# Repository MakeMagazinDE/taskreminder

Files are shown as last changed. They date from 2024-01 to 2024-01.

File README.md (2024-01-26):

GitHub Logo

Maker Media GmbH
*** 

# Task-Reminder

### Aufgaben, die man nicht im Blick hat, können schnell mal unter den Tisch fallen. Den Task-Reminder mit seinen LEDs kann man jedoch kaum übersehen. Er weiß genau, welche Aufgabe als Nächstes ansteht und leuchtet unermüdlich, bis man sie erledigt hat.

Ergänzend zum Artikel aus der Make 1/24 findest du hier die benötigten MicroPython-Programme für den ESP32, die Formeln für das Google-Sheet sowie die CAD-Daten für die Platine und das Gehäuse des Task-Reminders.

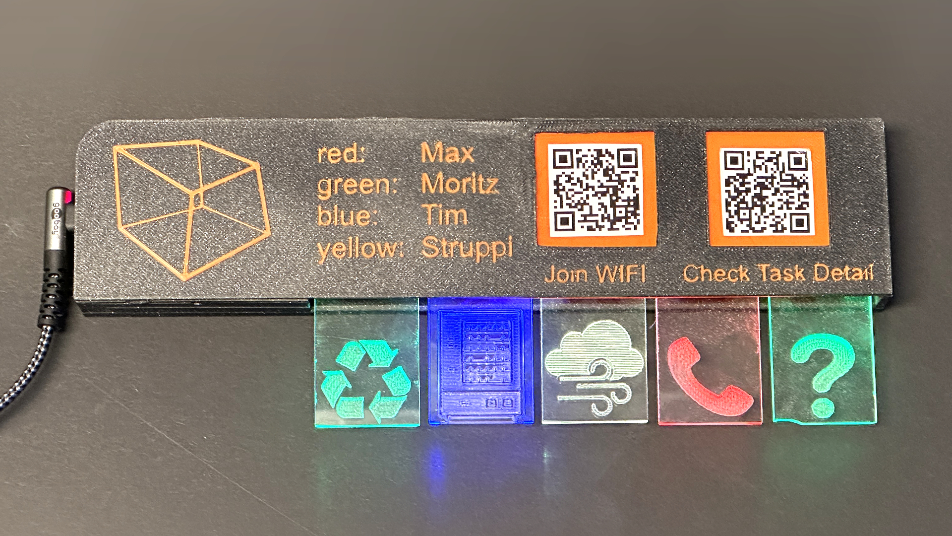
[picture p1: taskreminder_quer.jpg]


Den Artikel mit der Bauanleitung gibt es in der **[Make-Ausgabe 1/24](https://www.heise.de/select/make/2024/1)** zu lesen.

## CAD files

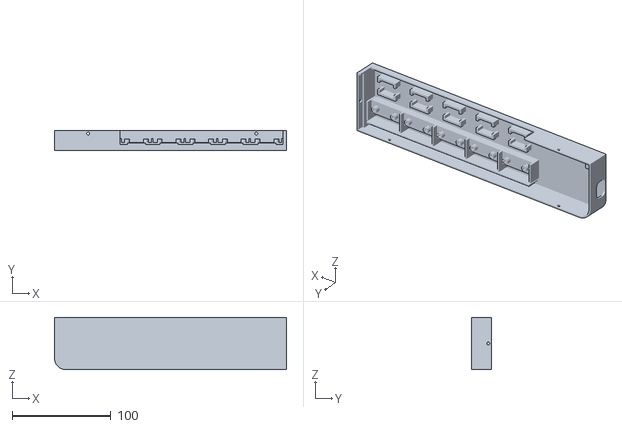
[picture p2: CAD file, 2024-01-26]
CAD/Base.stl
234.8 x 20.0 x 52.8

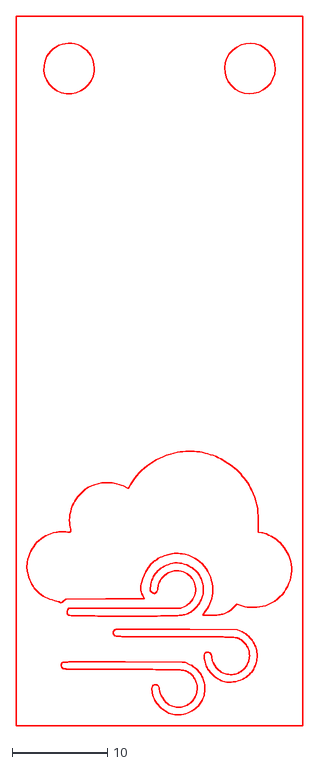
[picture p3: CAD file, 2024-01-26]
CAD/Symbol_FreshAir.dxf
30.1 x 74.5

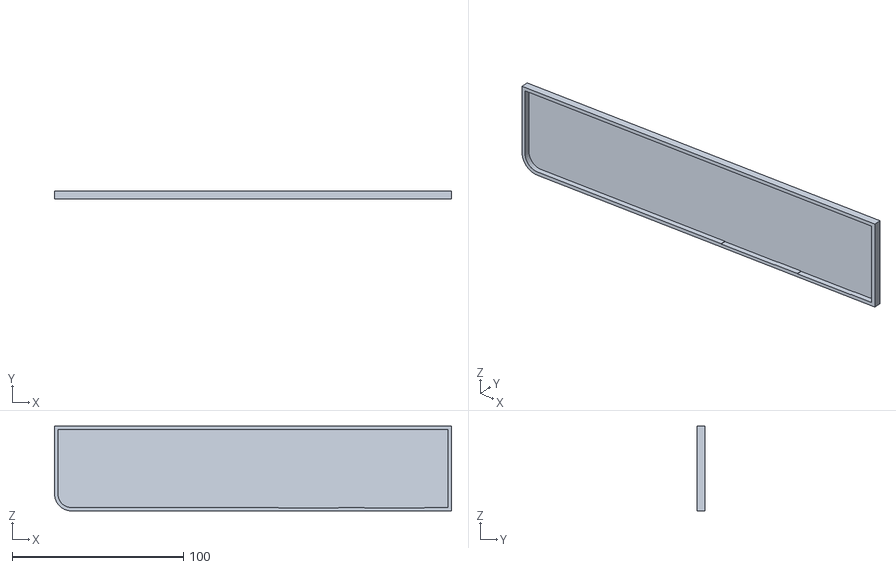
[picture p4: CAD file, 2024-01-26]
CAD/Cover_base.stl
231.6 x 4.40 x 49.6

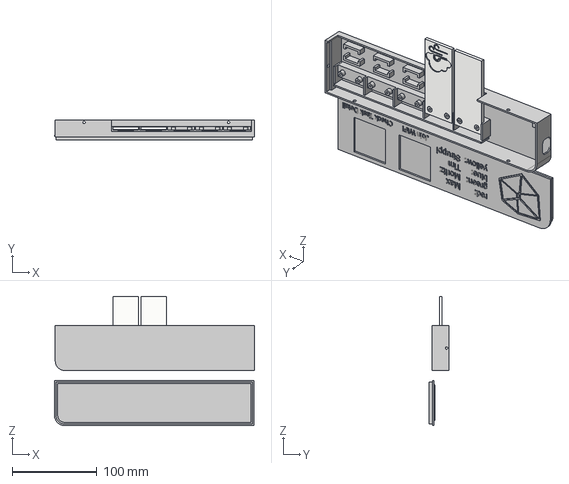
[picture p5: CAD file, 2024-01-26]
CAD/Task_Reminder.step
235.6 x 24.0 x 152.1 mm

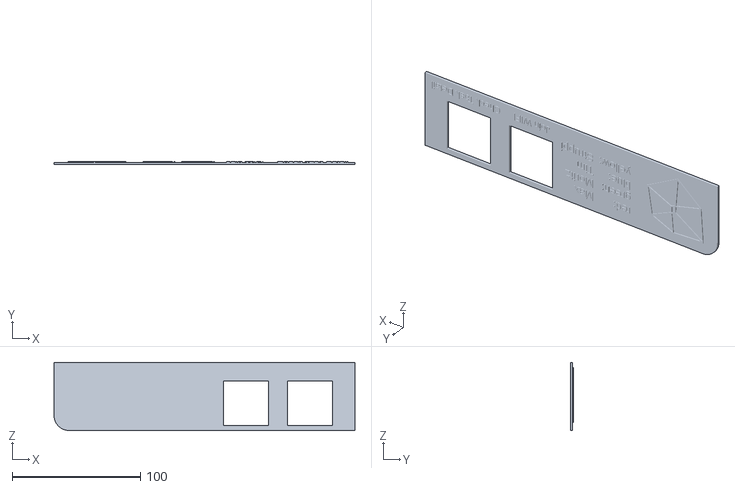
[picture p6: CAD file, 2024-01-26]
CAD/Cover_Top.stl
235.2 x 2.60 x 53.2

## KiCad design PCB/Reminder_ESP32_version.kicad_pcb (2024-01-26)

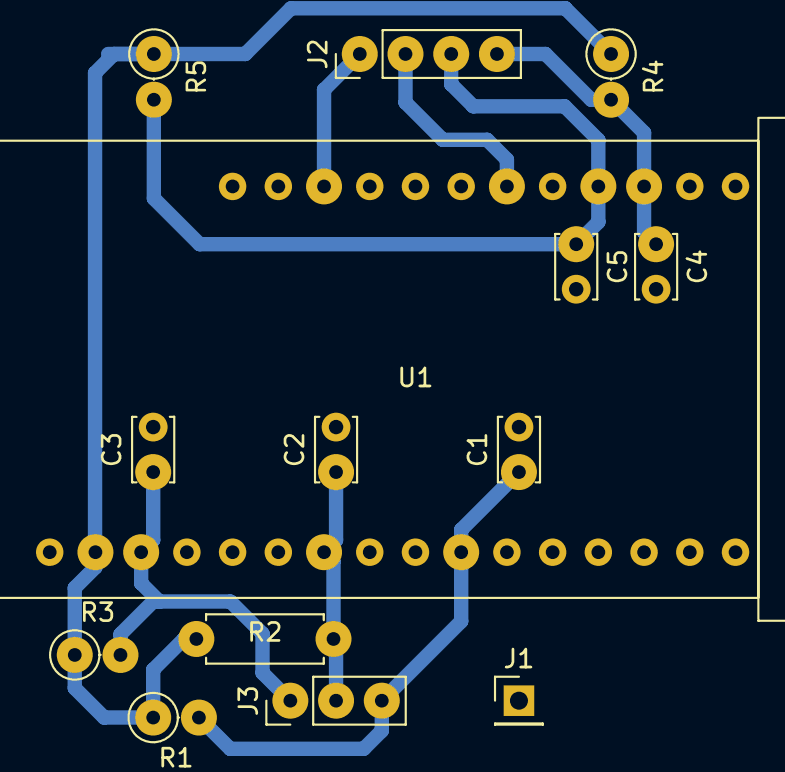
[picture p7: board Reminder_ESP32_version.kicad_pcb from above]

Board: 2 copper layers, 14 parts (0 on the bottom side), 9 nets.

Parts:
C1, C2, C3, C4, C5: 100nF; C_Disc_D3.4mm_W2.1mm_P2.50mm
J1: Conn_01x01_Female; PinHeader_1x01_P2.54mm_Vertical
J2: Conn_01x04_Female; PinHeader_1x04_P2.54mm_Vertical
J3: Conn_01x03_Female; PinHeader_1x03_P2.54mm_Vertical
R1, R3, R4, R5: 1k; R_Axial_DIN0207_L6.3mm_D2.5mm_P2.54mm_Vertical
R2: 1k; R_Axial_DIN0207_L6.3mm_D2.5mm_P7.62mm_Horizontal
U1: ESP32_ePulse_Feather; ESP32 ePulse Feather

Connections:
+3.3V: R1.1, R2.1, R3.1, R4.1, R5.1, U1.14 (3V3)
GND: C1.2, C2.2, C3.2, C4.2, C5.2, J1.1, U1.16 (GND)
unnamed: C3.1, J3.1, R3.2, U1.15 (02)
unnamed: C4.1, J2.4, R4.2, U1.3 (14_CLK)
unnamed: C5.1, J2.3, R5.2, U1.4 (32)
unnamed: J2.1, U1.10 (USB)
unnamed: J2.2, U1.6 (33)
unnamed: C2.1, J3.2, R2.2, U1.19 (34)
unnamed: C1.1, J3.3, R1.2, U1.22 (04)

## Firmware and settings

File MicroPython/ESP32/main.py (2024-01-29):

import machine
import time
import urequests as requests
import neopixel
import utime
import ujson
import _thread
try:
    import usocket as socket
except:
    import socket

# Google Sheets "Apps Script"-URLs für POST and GET Aufruf:
# Kopiere die "Apps Script"-URLs in die folgenden beiden Zeilen
UPLOAD_URL = 'Hier URL einsetzen'        # Anpassen !!!
DOWNLOAD_URL = 'Hier URL einsetzen'     # Anpassen !!!

# Konfiguration der ESP32 IO-Pins zum Anschluss der Taster
BUTTON_PINS = [2, 34, 4, 14, 32] #entspricht SW1, SW2, SW3, SW4, SW5
 
# Konfiguration der Spaltenüberschriften im Google-Sheet
# Nicht ändern, da sonst auch das Google-Script angepasst werden muss
# Spaltenüberschriften im Blatt „LED_Status":
HEADER_ICON = "ICON"
HEADER_TIME = "DUE_TIME"
HEADER_TITEL = "TITEL"
HEADER_STATUS = "STATUS"
HEADER_COLOR = "COLOR"
HEADER_ROW_ID = "ROW_ID"

# Spaltenüberschriften und spezielle Werte im Blatt „Aufgabenliste":
HEADER_WATCHDOG = "WatchDog"       #Wird benötigt um eine Status-Neuberechnung im Google Sheet zu erzwingen
HEADER_TASK_STATUS = "Task_Status" #In dieser Spalte wird der Wert "done" eingetragen, wenn die Aufgabe erledigt wurde
VALUE_COMPLETED = "done"           #Wert der in obige Spalte eingetragen werden soll

# Neopixel Konfiguration
NUM_PIXELS = 10    #Anzahl der LEDs im NeoPixel-Streifen
NEOPIXEL_PIN = 33  #ESP32-IO-Pin, an dem der NeoPixel-Streifen angeschlossen ist
UPDATE_CYCLE = 60  #Zeitintervall in Sekunden zwischen den Abfragen des neuen Status im Google Sheet

# Configure the pin for NeoPixel data
pin = machine.Pin(NEOPIXEL_PIN, machine.Pin.OUT)

# Create a NeoPixel object
pixels = neopixel.NeoPixel(pin, NUM_PIXELS)

led_states = []  # List to store the state and color of each LED
LED_UPDATE_NEEDED = True
PIN_PRESSED = -1
LAST_STATE = False
last_update = time.mktime((0, 0, 0, 0, 0, 0, 0, 0, -1))


# Funktion für die Webseite zur Umbennenung von deutschen Umlauten, die sonst falsch dargestellt würden.
def replace_german_chars(text):
    replacements = {
        "ü": "&uuml;",
        "ö": "&ouml;",
        "ä": "&auml;",
        "Ö": "&Ouml;",
        "Ä": "&Auml;",
        "Ü": "&Uuml;",
        # Add more character replacements as needed
    }
    for char, replacement in replacements.items():
        text = text.replace(char, replacement)
    return text

# Funktion für die Webseite um neben dem Icon auch die Fälligkeitszeit anzuzeigen  
def AddTimeToIcon(TimeString):
    if TimeString > "00:00":
        TimeString = ' @ ' + TimeString
    else:
        TimeString = ''
    return TimeString

# Webseite, die die anstehenden Aufgaben in tabellarischer Form darstellt
def web_page():
    html = """<!DOCTYPE HTML><html>
<head>
  <meta name="viewport" content="width=device-width, initial-scale=1">
    <style>
    html { font-family: Arial; display: inline-block; margin: 0px auto; text-align: left;    }
    h2 { font-size: 1.5rem; } p { font-size: 1.5rem; }
    .units { font-size: 2.0rem; }
    .dht-labels{ font-size: 1.0rem; vertical-align:bottom; padding-bottom: 0px; }
  </style>
</head>
<body>
  <h2>Family Reminder</h2>
  <p>
    <span><strong>""" + replace_german_chars(led_status[0][HEADER_ICON]) + AddTimeToIcon(led_status[0][HEADER_TIME]) + """</strong></span>
  </p>
  <p>
    <span>""" + replace_german_chars(led_status[0][HEADER_TITEL]) + """</span>
  </p>
  <p>
    <span><strong>""" + replace_german_chars(led_status[1][HEADER_ICON]) + AddTimeToIcon(led_status[1][HEADER_TIME]) + """</strong></span>
  </p>
  <p>
    <span>""" + replace_german_chars(led_status[1][HEADER_TITEL]) + """</span>
  </p>
  <p>
    <span><strong>""" + replace_german_chars(led_status[2][HEADER_ICON]) + AddTimeToIcon(led_status[2][HEADER_TIME]) + """</strong></span>
  </p>
  <p>
    <span>""" + replace_german_chars(led_status[2][HEADER_TITEL]) + """</span>
  </p>
  <p>
    <span><strong>""" + replace_german_chars(led_status[3][HEADER_ICON]) + AddTimeToIcon(led_status[3][HEADER_TIME]) + """</strong></span>
  </p>
  <p>
    <span>""" + replace_german_chars(led_status[3][HEADER_TITEL]) + """</span>
  </p>
  <p>
    <span><strong>""" + replace_german_chars(led_status[4][HEADER_ICON]) + AddTimeToIcon(led_status[4][HEADER_TIME]) + """</strong></span>
  </p>
  <p>
    <span>""" + replace_german_chars(led_status[4][HEADER_TITEL]) + """</span>
  </p>

</body>
</html>"""
    
    return html


        
# Funktion zur Erstellung einer neuen Aufgabe oder zum Status-Update einer bestehenden Aufgabe    
def call_google_apps_script(data):
    # Convert the JSON data to a string
    data_str = ujson.dumps(data)

    # Make a POST request
    response = requests.request("POST", UPLOAD_URL , data=data_str)
    return response

# Funktion zur Abfrage des LED-Status in im Google Sheet "LED_Status"    
def fetch_led_status():
    response = ujson.loads(requests.get(DOWNLOAD_URL).text)
    return response 



# Funktion zur Ansteuerung der NeoPixel, für jedes Icon werden zwei aufeinander folgende Pixel angesteuert
def set_neopixel_colors(json_data):
    data = json_data #ujson.loads(json_data)

    for i in range(len(data)):
        if data[i][HEADER_STATUS] == "on":
            color = data[i][HEADER_COLOR]
            pixel_index = i * 2  # Two pixels per ID

            # Set color for the first pixel
            pixels[pixel_index] = parse_color(color)

            # Set color for the second pixel
            pixels[pixel_index + 1] = parse_color(color)
        elif data[i][HEADER_STATUS] == "off":
            pixel_index = i * 2  # Two pixels per ID

            # Switch off the first pixel
            pixels[pixel_index] = (0, 0, 0)

            # Switch off the second pixel
            pixels[pixel_index + 1] = (0, 0, 0)

    # Update NeoPixel strip
    pixels.write()


def parse_color(color):
    color_mapping = {
        "red": (255, 0, 0),
        "green": (0, 255, 0),
        "blue": (0, 0, 255),
        "yellow": (255, 255, 0)
        # Add more color mappings as needed
    }
    return color_mapping.get(color, (0, 0, 0))  # Default to (0, 0, 0) if color is not found in the mapping



# Function to handle incoming connections
def handle_connection(conn):
    request = conn.recv(1024)
    response = web_page()
    conn.sendall(response)
    conn.close()

# Interrupt-Funktion um die aktiven LEDs blinken zu lassen
def LED_timer_interrupt(timer1):
    global LAST_STATE
    global led_status
    if LAST_STATE:
        LAST_STATE = False
        for i in range(len(led_status)):
            if led_status[i][HEADER_STATUS] == "on" :
                pixels[i*2] = parse_color(led_status[i][HEADER_COLOR])
                pixels[i*2+1] = parse_color(led_status[i][HEADER_COLOR])
            else:
                pixels[i*2] = (0, 0, 0)
                pixels[i*2+1] = (0, 0, 0)
    else:
        LAST_STATE = True
        for i in range(NUM_PIXELS):
            pixels[i] = (0, 0, 0)
    pixels.write()
    return []        

def button_interrupt(pin):
    def handle_interrupt(p):
        global PIN_PRESSED
        PIN_PRESSED = pin
    return handle_interrupt

buttons = []
for pin in BUTTON_PINS:
    button = machine.Pin(pin, machine.Pin.IN, machine.Pin.PULL_UP)
    buttons.append(button)
    button.irq(trigger=machine.Pin.IRQ_RISING, handler=button_interrupt(pin))

led_status = fetch_led_status()

# Interrupt-Konfiguration zum Blinkenlassen der LEDs. Die Raute vor den folgenden zwei Zeilen entfernen,
# wenn die LEDsblinken sollen
#timer1 = machine.Timer(0)
#timer1.init(period=1000, mode=machine.Timer.PERIODIC, callback=LED_timer_interrupt)

# Initialisierung der Webseite
s = socket.socket(socket.AF_INET, socket.SOCK_STREAM)
s.bind(('', 80))
s.listen(5)
s.setblocking(False)  # Set the socket to non-blocking mode
  


TICK = True
while True:
    # Wurde ein Taster gedrückt, wird die entsprechende Tasternummer (0-4) in der Variablen PIN_PRESSED gespeichert
    if (PIN_PRESSED > -1):
        #Gibt einen VALUE_COMPLETED zwischen 0 und 4 zurück, der die gedrückte Taste representiert
        button_index = BUTTON_PINS.index(PIN_PRESSED)
        print("ButtonIndex:", button_index )
        
        #In der Spalte „Row_ID“ im Blatt „LED_STATUS“ wird die Zeile der Aufgabe aus der Aufgabenliste gespeichert
        #Die folgende Zeile ruft das Google Apps-Skript auf, um in der Spalte COLUMN_COMPLETED den Status der oben genannten Aufgabe in „done“ zu ändern.
        WriteResponse = call_google_apps_script({HEADER_ROW_ID: led_status[button_index][HEADER_ROW_ID],HEADER_TASK_STATUS:VALUE_COMPLETED})
        print(WriteResponse.text)
        LED_UPDATE_NEEDED = True
        PIN_PRESSED = -1
        print(WriteResponse)

    # Abfrage des aktuellen Status aus dem Google Sheet "LED_Status" nach Ablauf der Zeit UPDATE_CYCLE. Damit Formelwerte neu berechnet werden, wird abwechselnd der
    # Wert Tick oder Tack in den Spalte Watchdog geschrieben. 
    if (time.time() - last_update) > UPDATE_CYCLE or LED_UPDATE_NEEDED:
        if TICK:
            str_tick = "TICK"
        else:
            str_tick = "TACK"
        WriteResponse = call_google_apps_script({HEADER_ROW_ID: "2",HEADER_WATCHDOG:str_tick})  #Call only needed to trigger data update in Google Sheet
        print(WriteResponse.text)
        TICK = not TICK
        led_status = fetch_led_status()
        print("LEDstatus: ", led_status)
        set_neopixel_colors(led_status)
        LED_UPDATE_NEEDED = False
        last_update = time.time()
        #print(led_states)


    time.sleep(1)
    print('.', end='')
    try:
        conn, addr = s.accept()  # Accept an incoming connection if available
        _thread.start_new_thread(handle_connection, (conn,))  # Start a new thread to handle the connection
    except OSError:
        pass

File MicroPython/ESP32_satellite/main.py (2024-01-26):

import machine
import time
import ujson
import urequests as requests

# Google Sheets "Apps Script"-URLs für POST:
UPLOAD_URL = 'Hier URL einsetzen'        # Anpassen !!!

# Konfiguration der Spaltenüberschriften im Google-Sheet
# Nicht ändern, da sonst auch das Google-Script angepasst werden muss
# Spaltenüberschriften im Blatt „LED_Status":
HEADER_ICON = "Icon:"
HEADER_TIME = "Um (optional) :"
HEADER_DATE = "Faellig am:"
HEADER_TITEL = "Aufgabenbeschreibung:"
HEADER_COLOR = "Farbe:"
HEADER_ROW_ID = "ROW_ID"
HEADER_EMAIL = "Email address"

# Define the pin number where the sensor is connected
sensor_pin = machine.Pin(39)
adc = machine.ADC(sensor_pin)

# Funktion zur Erstellung einer neuen Aufgabe oder zum Status-update einer bestehenden Aufgabe    
def Today_as_String():

    # Get the current time in seconds
    current_time = time.time()

    # Convert the time to a tuple representing local time
    current_local_time = time.localtime(current_time)

    # Extract the date components
    year = current_local_time[0]
    month = current_local_time[1]
    day = current_local_time[2]

    # Create the date string in the format "dd/mm/yyyy"
    date_string = "{:02d}/{:02d}/{:04d}".format(day, month, year)

    # Print the date string
    return date_string

def call_google_apps_script(data):
    # Convert the JSON data to a string
    data_str = ujson.dumps(data)

    # Make a POST request
    response = requests.request("POST", UPLOAD_URL , data=data_str)
    return response

# Function to read soil moisture data from the sensor
def read_soil_moisture():
    # Read analog value from the sensor
    sensor_value = adc.read()
    
    # Convert the analog value to a percentage (0-100%)
    moisture_percentage = 100 - ((sensor_value / 1023) * 100)
    
    return moisture_percentage

# Main loop
while True:
    # Read soil moisture
    moisture = read_soil_moisture()
   
    # Print the moisture value
    print("Soil Moisture: {:.2f}%".format(moisture))
    if (moisture > 50):
        # Erstelle neue Aufgabe in Aufgabenliste mit folgenden Werten:
        WriteResponse = call_google_apps_script({ HEADER_ICON: "3-Giessen", HEADER_TITEL: "Rosen giessen",
                                                  HEADER_DATE: Today_as_String(), HEADER_EMAIL: "ESP32@Rosen", HEADER_COLOR: "blue"})  
        print(WriteResponse.text)
        time.sleep(60*60*12) # Aufgabe wurde erstellt, warte 12h vor der nächsten Messung
     
    # Delay for 3 seconds
    time.sleep(3)
